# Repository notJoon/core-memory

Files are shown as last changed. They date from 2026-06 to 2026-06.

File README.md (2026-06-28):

# core-memory
ferrite core memory PCB &amp; firmware

## Gerber Files

Pre-generated Gerber files are in the `gerber/` directory and can be submitted to a PCB fabricator directly.

| File | Layer |
|---|---|
| `CoreMem-F_Cu.gbr` | Front copper |
| `CoreMem-B_Cu.gbr` | Back copper |
| `CoreMem-F_Mask.gbr` | Front solder mask |
| `CoreMem-B_Mask.gbr` | Back solder mask |
| `CoreMem-F_SilkS.gbr` | Front silkscreen |
| `CoreMem-B_SilkS.gbr` | Back silkscreen |
| `CoreMem-Edge_Cuts.gbr` | Board outline |
| `CoreMem-PTH.drl` | Plated drill holes |
| `CoreMem-NPTH.drl` | Non-plated drill holes |

Zip the contents of `gerber/` and upload the archive to your fabricator (JLCPCB, PCBWay, OSH Park, etc.).

### Regenerating Gerber Files

If you modify `CoreMem.kicad_pcb`, regenerate the files with KiCad 5 or later.

**Prerequisites:** [KiCad](https://www.kicad.org/) 5.x or later

1. Open `CoreMem.kicad_pcb` in KiCad PCB Editor (Pcbnew).
2. Go to **File** and select **Plot**.
3. Set the output directory to `gerber/`.
4. Select the following layers: `F.Cu`, `B.Cu`, `F.SilkS`, `B.SilkS`, `F.Mask`, `B.Mask`, `Edge.Cuts`.
5. Make sure **Use Protel filename extensions** is unchecked and **Generate Gerber job file** is unchecked.
6. Click **Plot**.
7. Click **Generate Drill Files**, keep the defaults, and click **Generate Drill File**.
8. Zip the `gerber/` directory and submit to your fabricator.

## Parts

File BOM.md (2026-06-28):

# Bill of Materials

## 능동 소자

| 수량 | 부품 | 설명 | 지정 파트 넘버 | 대안 부품 | 비고 |
|---|---|---|---|---|---|
| 2 | ICE40HX4K-TQ144 | FPGA | | | |
| 12 | OPA2365AIDR | 센스 앰프용 Op-Amp | | | |
| 10 | TS864 | 쿼드 비교기 | | TS864IDT | 동일 SOIC-14, 산업용 온도 범위(-40~85°C), 직접 교체 가능 |
| 20 | DMG6602SVTQ-7 | 듀얼 N+P ch MOSFET (드라이브) | | | |
| 6 | DMHC3025LSD-13 | 듀얼 P-ch MOSFET | | | |
| 4 | QS5K2 | N-ch MOSFET 어레이 | | | |
| 1 | DMG1012T-7 | N-ch MOSFET (SOT-523) | | | |
| 1 | MCP42010 | 듀얼 디지털 포텐시오미터 | MCP42010-I/SL | MCP42010-E/SL | MCP42010-E/P는 PDIP-14(스루홀)이므로 사용 불가 |
| 1 | W25Q32JVSSIQ_TR | 32Mbit SPI NOR Flash (FPGA 설정 저장) | | GD25Q32CSIG, GD25Q32ESIG, MX25L3206EM2I-12G, W25Q32FVSSIG, AT25SF321B-SHD-B | 단종. 대안 부품은 모두 SOIC-8 와이드(5.6mm) 패키지 확인 필수 |
| 1 | SiT2001B | 13.333MHz MEMS 오실레이터 | | | |
| 1 | LM338 | 조정형 LDO 5A (VDRIVE) | LM338T/NOPB | | 회로도에 이미 LM338T/NOPB 지정 |
| 1 | AZ1117-3.3 | 3.3V LDO | AZ1117EH-3.3TRG1 | | AZ1117CH-3.3TRG1은 패키지 불일치 가능성 있음(SOT-89 추정). 반드시 데이터시트에서 SOT-223 여부 확인 후 사용 |
| 1 | AZ1117-1.2 | 1.2V LDO | AZ1117EH-1.2TRG1 | | |

## 수동 소자

| 수량 | 부품 | 값 | 비고 |
|---|---|----|---|
| 24 | 저항 | 22k | |
| 15 | 저항 | 10k | |
| 14 | 저항 | 20Ω | |
| 8 | 저항 | 1k | |
| 4 | 저항 | 261Ω | |
| 4 | 저항 | 100Ω | |
| 1 | 저항 | 100k | |
| 2 | 트리머 저항 | 10k | |
| 2 | 저항 | 0Ω (점퍼) | |
| 2 | 저항 | DNP | 미실장 |
| 28 | 세라믹 커패시터 | 0.1uF | |
| 15 | 세라믹 커패시터 | 10uF | |
| 6 | 전해 커패시터 | 100uF | |
| 1 | 다이오드 | CDBU0520 | |
| 4 | LED | | 색상 임의 |

## 커넥터 및 기구

| 수량 | 부품 | 설명 |
|---|---|---|
| 1 | Conn 1x6 2.54mm | CTRL 커넥터 |
| 1 | Conn 2x4 2.54mm | PROG (FPGA 프로그래밍) |
| 1 | Conn 2x2 2.54mm | 기타 커넥터 |
| 1 | CoreArray | 코어 메모리 어레이 (수작업 권선) |

## 주의사항

- **FET 게이트 풀다운 누락**: `X0/X1_EN_F/R`, `Y0~Y3_EN_F/R` 신호(총 12개)에 풀다운 저항이 없음. FPGA 미설정 시 shoot-through 발생 가능. 10kΩ 저항 12개를 보드 수령 후 몸지 납땜으로 추가 권장 (위 BOM에 미포함).
- **W25Q32JVSSIQ_TR**: 단종 부품. 대안 부품 선택 시 SOIC-8 와이드(5.6mm) 패키지인지 반드시 확인.
- **AZ1117CH-3.3TRG1**: SOT-89 패키지로 추정되며 PCB 풋프린트(SOT-223-3)와 다를 수 있음. 구매 전 데이터시트 확인 필수.

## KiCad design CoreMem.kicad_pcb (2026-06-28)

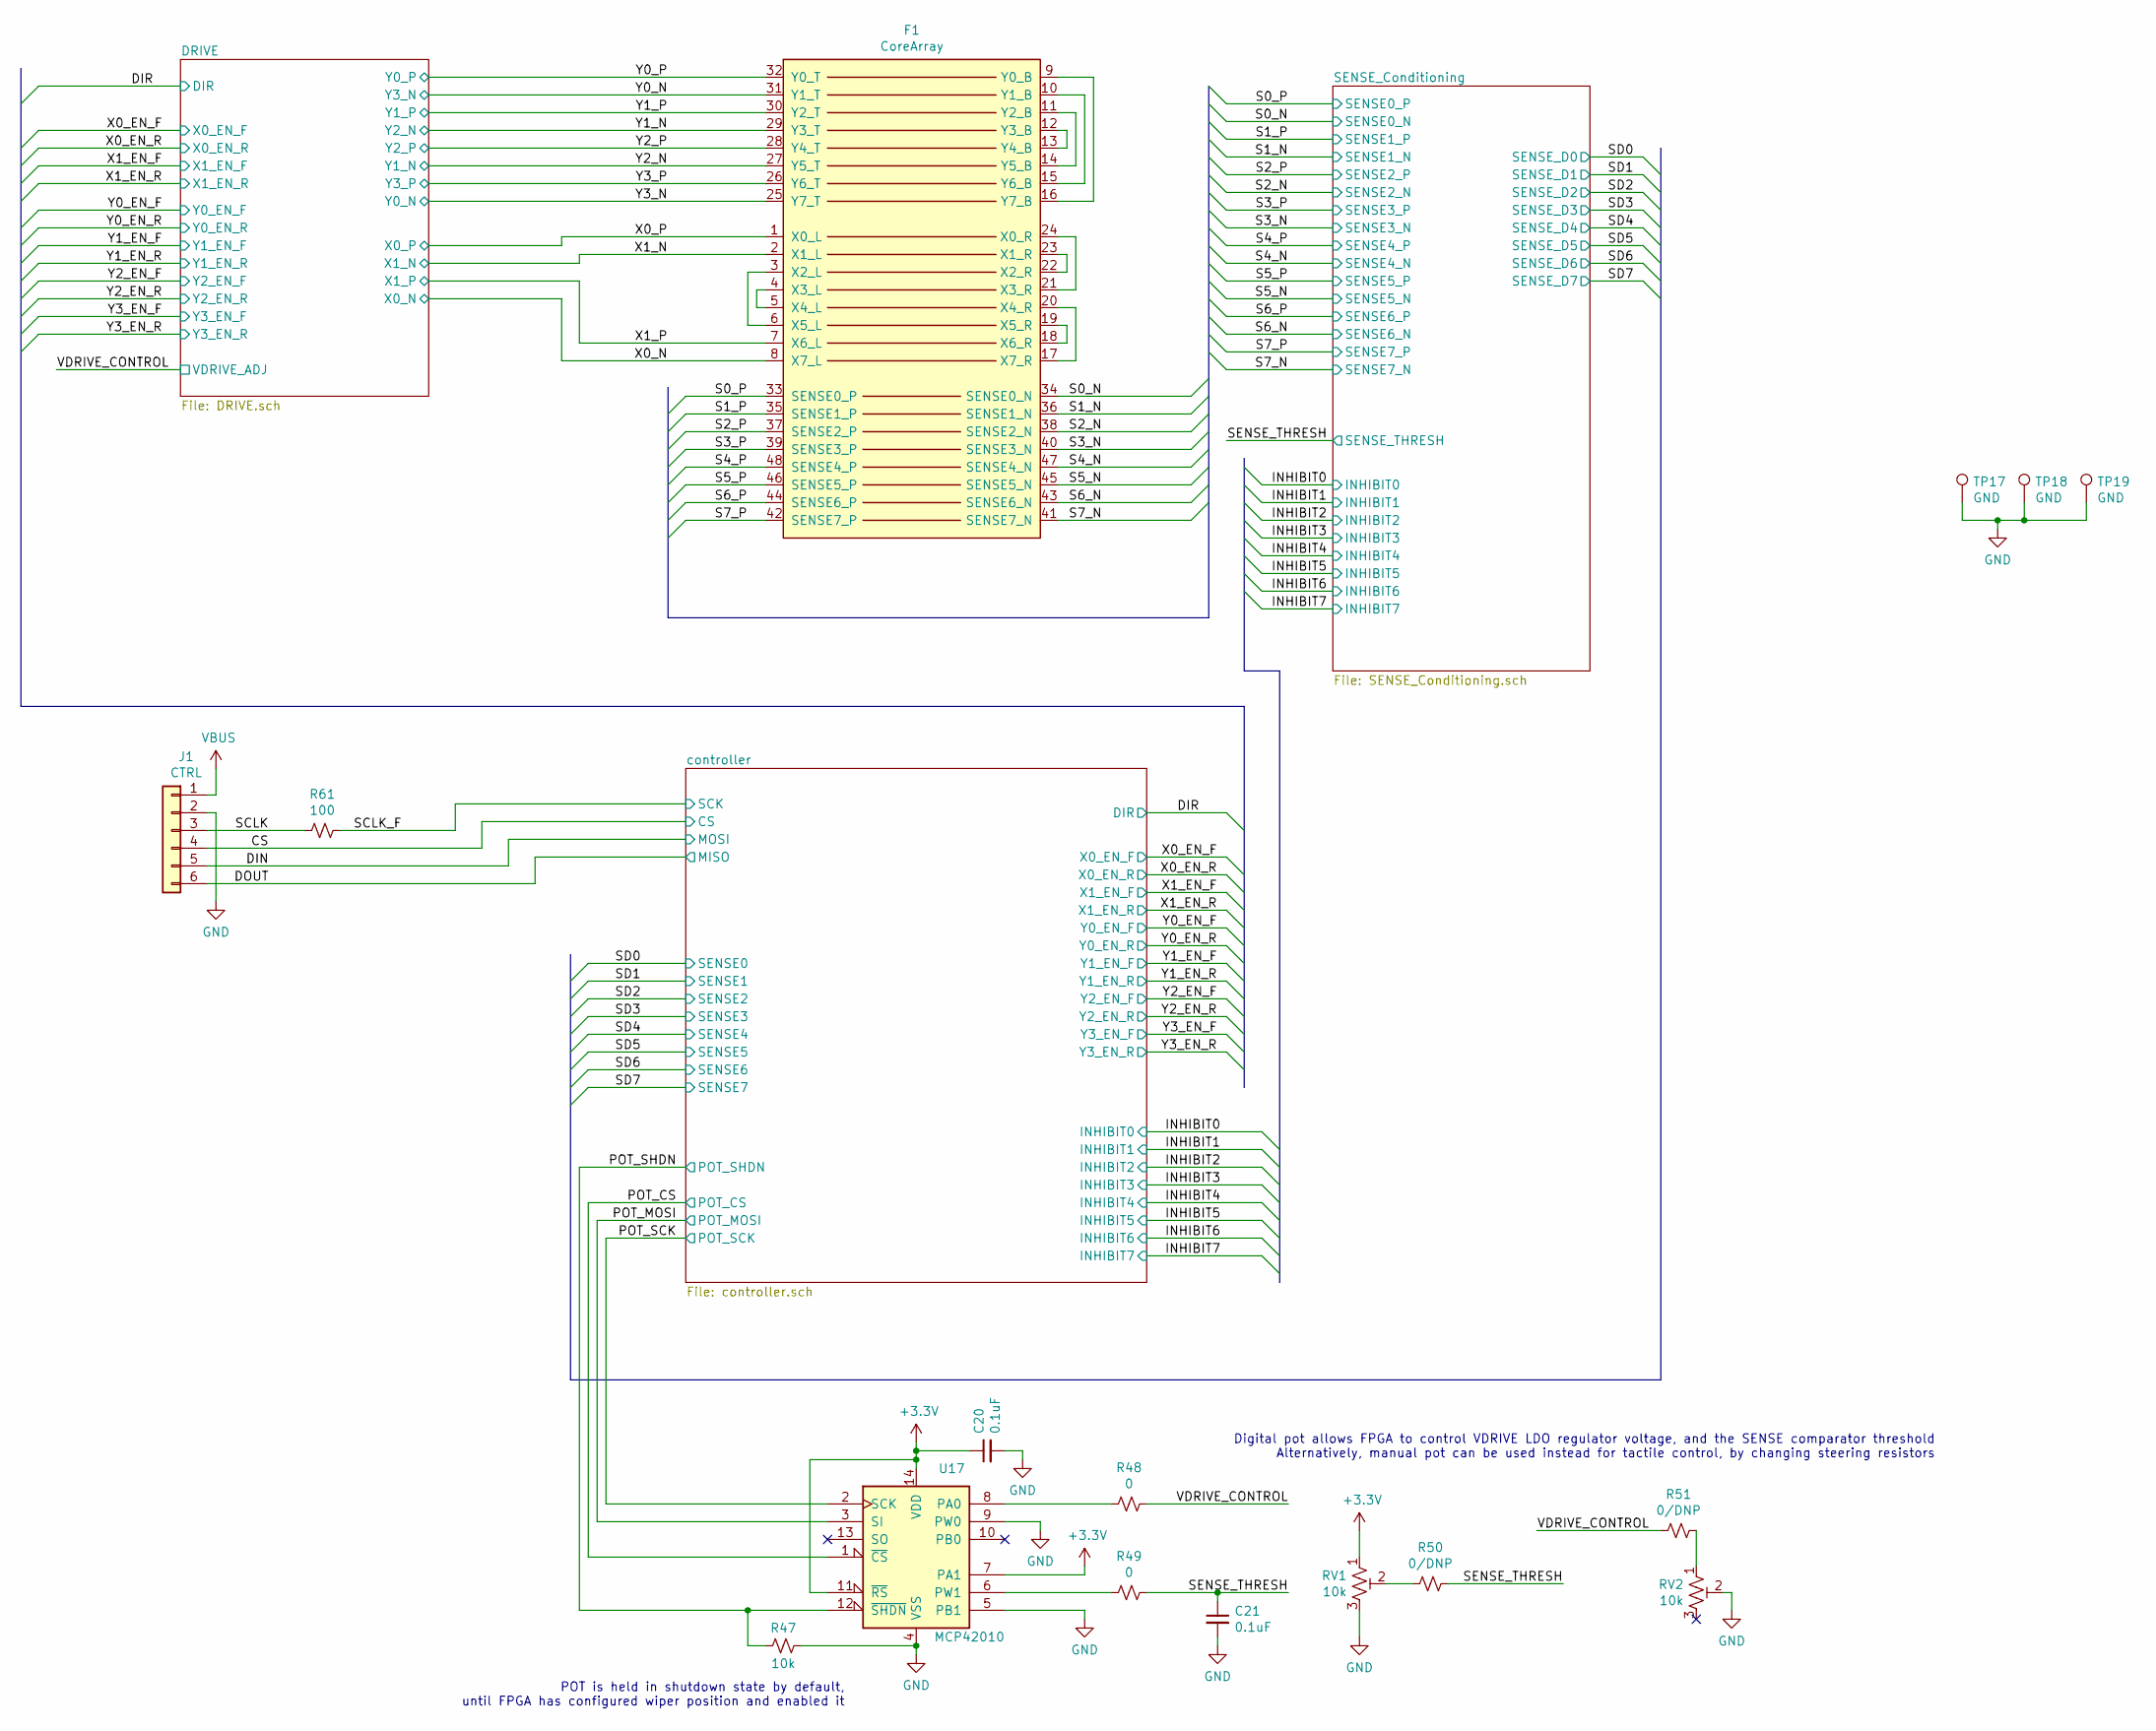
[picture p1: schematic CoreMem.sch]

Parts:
C20, C21: 0.1uF; C_0603_1608Metric_Pad1.05x0.95mm_HandSolder; Mfg Part Number CL10B104KA8NNNC
F1: CoreArray
J1: CTRL; PinHeader_1x06_P2.54mm_Vertical; Mfg Part Number 68000-406HLF
R47: 10k; R_0603_1608Metric_Pad1.05x0.95mm_HandSolder; Mfg Part Number ERJ-3EKF1002V
R48, R49: 0; R_0603_1608Metric_Pad1.05x0.95mm_HandSolder; Mfg Part Number ERJ-3GEY0R00V
R50, R51: 0/DNP; R_0603_1608Metric_Pad1.05x0.95mm_HandSolder; Mfg Part Number ERJ-3GEY0R00V
R61: 100; R_0603_1608Metric_Pad1.05x0.95mm_HandSolder; Mfg Part Number ERJ-3EKF1000V
RV1, RV2: 10k; ST4EB; Mfg Part Number ST4ETB103
TP17, TP18, TP19: GND; PinHeader_1x01_P2.54mm_Vertical
U17: MCP42010; SOIC-14_3.9x8.7mm_P1.27mm; Mfg Part Number MCP42010-I/SL

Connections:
+3V3: C20.1, RV1.1, U17.7 (PA1), U17.11 (~RS), U17.14 (VDD); also elsewhere on the board
/CS: J1.4; also elsewhere on the board
/DIN: J1.5; also elsewhere on the board
/DOUT: J1.6; also elsewhere on the board
/POT_CS: U17.1 (~CS); also elsewhere on the board
/POT_MOSI: U17.3 (SI); also elsewhere on the board
/POT_SCK: U17.2 (SCK); also elsewhere on the board
/POT_SHDN: R47.1, U17.12 (~SHDN); also elsewhere on the board
/S0_N: F1.34 (SENSE0_N); also elsewhere on the board
/S0_P: F1.33 (SENSE0_P); also elsewhere on the board
/S1_N: F1.36 (SENSE1_N); also elsewhere on the board
/S1_P: F1.35 (SENSE1_P); also elsewhere on the board
/S2_N: F1.38 (SENSE2_N); also elsewhere on the board
/S2_P: F1.37 (SENSE2_P); also elsewhere on the board
/S3_N: F1.40 (SENSE3_N); also elsewhere on the board
/S3_P: F1.39 (SENSE3_P); also elsewhere on the board
/S4_N: F1.47 (SENSE4_N); also elsewhere on the board
/S4_P: F1.48 (SENSE4_P); also elsewhere on the board
/S5_N: F1.45 (SENSE5_N); also elsewhere on the board
/S5_P: F1.46 (SENSE5_P); also elsewhere on the board
/S6_N: F1.43 (SENSE6_N); also elsewhere on the board
/S6_P: F1.44 (SENSE6_P); also elsewhere on the board
/S7_N: F1.41 (SENSE7_N); also elsewhere on the board
/S7_P: F1.42 (SENSE7_P); also elsewhere on the board
/SCLK: J1.3, R61.2
/SCLK_F: R61.1; also elsewhere on the board
/SENSE_THRESH: C21.1, R49.1, R50.1; also elsewhere on the board
/VDRIVE_CONTROL: R48.1, R51.2; also elsewhere on the board
/X0_N: F1.8 (X7_L); also elsewhere on the board
/X0_P: F1.1 (X0_L); also elsewhere on the board
/X1_N: F1.2 (X1_L); also elsewhere on the board
/X1_P: F1.7 (X6_L); also elsewhere on the board
/Y0_N: F1.31 (Y1_T); also elsewhere on the board
/Y0_P: F1.32 (Y0_T); also elsewhere on the board
/Y1_N: F1.29 (Y3_T); also elsewhere on the board
/Y1_P: F1.30 (Y2_T); also elsewhere on the board
/Y2_N: F1.27 (Y5_T); also elsewhere on the board
/Y2_P: F1.28 (Y4_T); also elsewhere on the board
/Y3_N: F1.25 (Y7_T); also elsewhere on the board
/Y3_P: F1.26 (Y6_T); also elsewhere on the board
GND: C20.2, C21.2, J1.2, R47.2, RV1.3, RV2.2, TP17.1, TP18.1, TP19.1, U17.4 (VSS), U17.5 (PB1), U17.9 (PW0); also elsewhere on the board
unnamed: F1.3 (X2_L), F1.6 (X5_L)
unnamed: F1.4 (X3_L), F1.5 (X4_L)
unnamed: F1.10 (Y1_B), F1.15 (Y6_B)
unnamed: F1.11 (Y2_B), F1.14 (Y5_B)
unnamed: F1.12 (Y3_B), F1.13 (Y4_B)
unnamed: F1.9 (Y0_B), F1.16 (Y7_B)
unnamed: F1.17 (X7_R), F1.20 (X4_R)
unnamed: F1.18 (X6_R), F1.19 (X5_R)
unnamed: F1.21 (X3_R), F1.24 (X0_R)
unnamed: F1.22 (X2_R), F1.23 (X1_R)
unnamed: R48.2, U17.8 (PA0)
unnamed: R49.2, U17.6 (PW1)
unnamed: R50.2, RV1.2
unnamed: R51.1, RV2.1
VBUS: J1.1; also elsewhere on the board

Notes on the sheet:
Digital pot allows FPGA to control VDRIVE LDO regulator voltage, and the SENSE comparator threshold Alternatively, manual pot can be used instead for tactile control, by changing steering resistors
POT is held in shutdown state by default, until FPGA has configured wiper position and enabled it

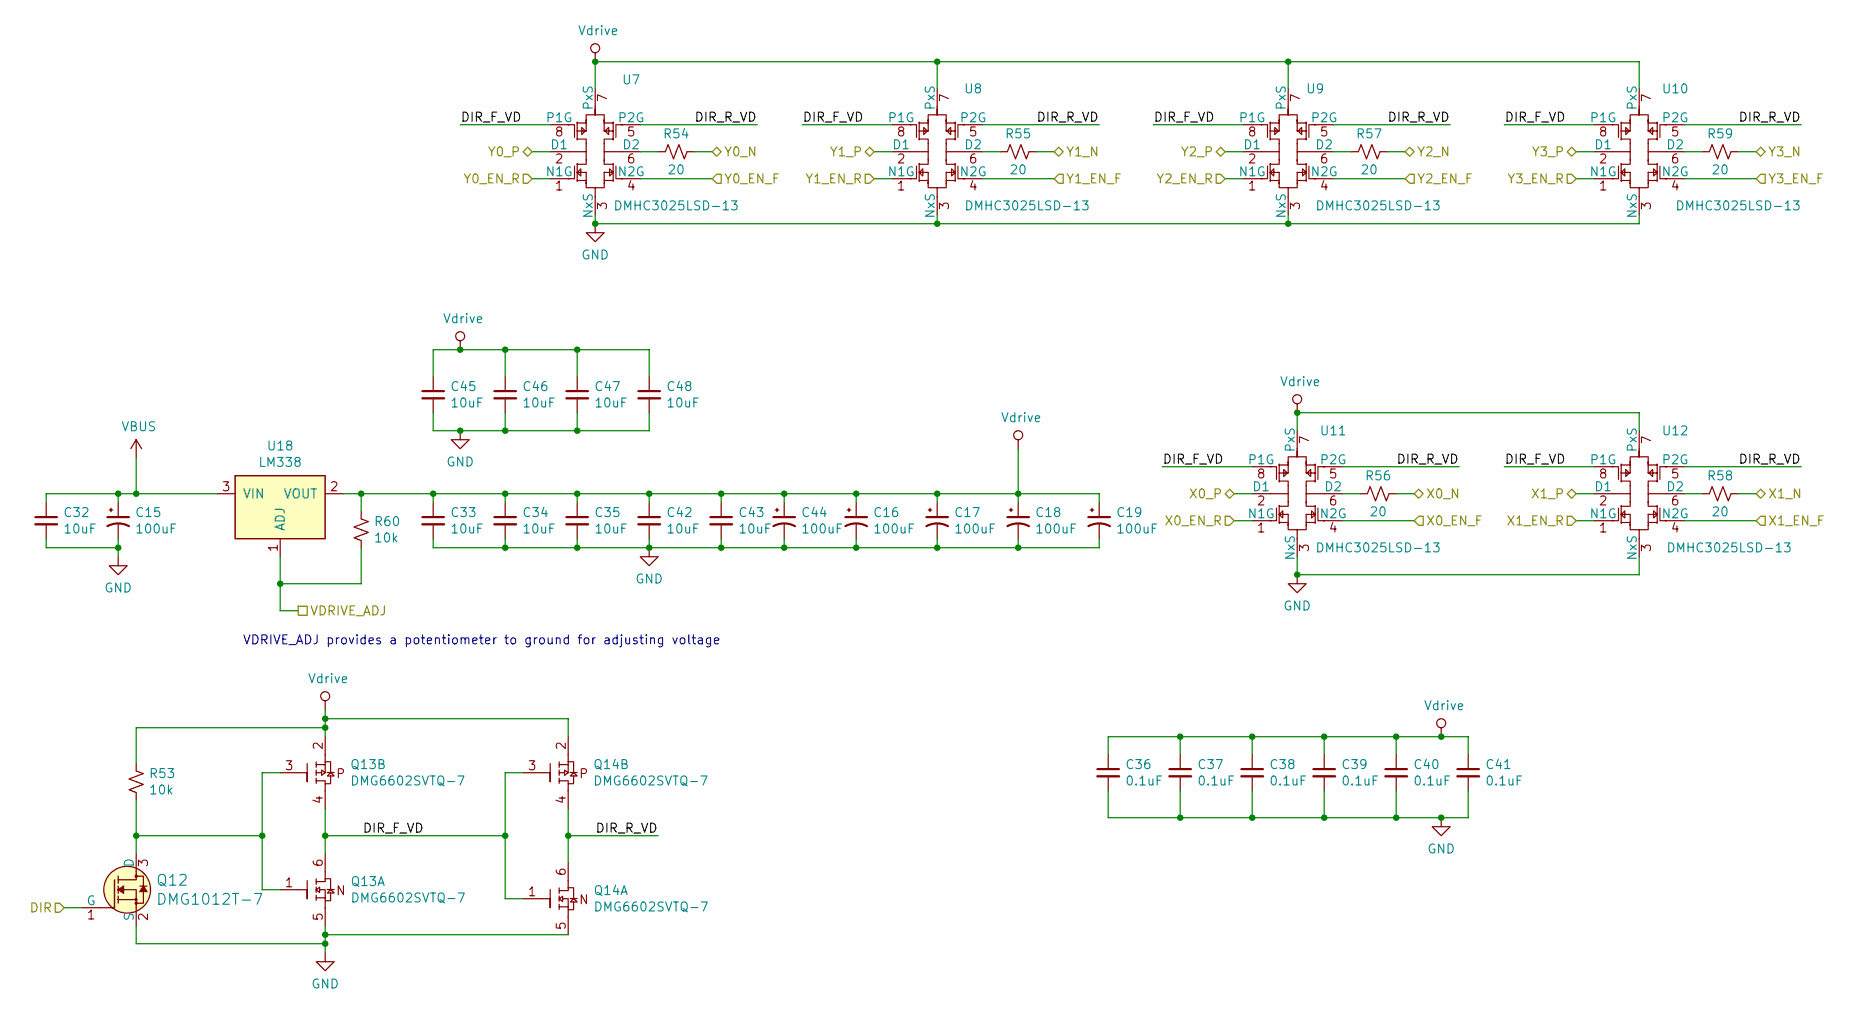
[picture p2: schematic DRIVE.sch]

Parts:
C15, C16, C17, C18, C19, C44: 100uF; C_Elec_6.3x7.7; Mfg Part Number UWT1E101MCL1GS
C32, C33, C34, C35, C42, C43, C45, C46, C47, C48: 10uF; C_1206_3216Metric_Pad1.42x1.75mm_HandSolder; Mfg Part Number CL31A106KAHNNNE
C36, C37, C38, C39, C40, C41: 0.1uF; C_0603_1608Metric_Pad1.05x0.95mm_HandSolder; Mfg Part Number CL10B104KA8NNNC
Q12: DMG1012T-7; SOT-523; MPN DMG1012T-7; Digi-Key_PN DMG1012T-7DICT-ND
Q13, Q14: DMG6602SVTQ-7; TSOT-23-6; Mfg Part Number DMG6602SVTQ-7
R53, R60: 10k; R_0603_1608Metric_Pad1.05x0.95mm_HandSolder; Mfg Part Number ERJ-3EKF1002V
R54, R55, R56, R57, R58, R59: 20; R_1206_3216Metric_Pad1.42x1.75mm_HandSolder; Mfg Part Number ESR18EZPF20R0
U7, U8, U9, U10, U11, U12: DMHC3025LSD-13‎; SOIC-8_3.9x4.9mm_P1.27mm; Mfg Part Number DMHC3025LSD-13
U18: LM338; TO-220-3_Vertical; Mfg Part Number LM338T/NOPB

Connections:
/DIR: Q12.1 (G); also elsewhere on the board
/DRIVE/DIR_F_VD: Q13.4 (D2), Q13.6 (D1), Q14.1 (G1), Q14.3 (G2), U7.8 (P1G), U8.8 (P1G), U9.8 (P1G), U10.8 (P1G), U11.8 (P1G), U12.8 (P1G)
/DRIVE/DIR_R_VD: Q14.4 (D2), Q14.6 (D1), U7.5 (P2G), U8.5 (P2G), U9.5 (P2G), U10.5 (P2G), U11.5 (P2G), U12.5 (P2G)
/VDRIVE_CONTROL: R60.2, U18.1 (ADJ); also elsewhere on the board
/X0_EN_F: U11.4 (N2G); also elsewhere on the board
/X0_EN_R: U11.1 (N1G); also elsewhere on the board
/X0_N: R56.1; also elsewhere on the board
/X0_P: U11.2 (D1); also elsewhere on the board
/X1_EN_F: U12.4 (N2G); also elsewhere on the board
/X1_EN_R: U12.1 (N1G); also elsewhere on the board
/X1_N: R58.1; also elsewhere on the board
/X1_P: U12.2 (D1); also elsewhere on the board
/Y0_EN_F: U7.4 (N2G); also elsewhere on the board
/Y0_EN_R: U7.1 (N1G); also elsewhere on the board
/Y0_N: R59.1; also elsewhere on the board
/Y0_P: U7.2 (D1); also elsewhere on the board
/Y1_EN_F: U8.4 (N2G); also elsewhere on the board
/Y1_EN_R: U8.1 (N1G); also elsewhere on the board
/Y1_N: R57.1; also elsewhere on the board
/Y1_P: U8.2 (D1); also elsewhere on the board
/Y2_EN_F: U9.4 (N2G); also elsewhere on the board
/Y2_EN_R: U9.1 (N1G); also elsewhere on the board
/Y2_N: R55.1; also elsewhere on the board
/Y2_P: U9.2 (D1); also elsewhere on the board
/Y3_EN_F: U10.4 (N2G); also elsewhere on the board
/Y3_EN_R: U10.1 (N1G); also elsewhere on the board
/Y3_N: R54.1; also elsewhere on the board
/Y3_P: U10.2 (D1); also elsewhere on the board
GND: C15.2, C16.2, C17.2, C18.2, C19.2, C32.2, C33.2, C34.2, C35.2, C36.2, C37.2, C38.2, C39.2, C40.2, C41.2, C42.2, C43.2, C44.2, C45.2, C46.2, C47.2, C48.2, Q12.2 (S), Q13.5 (S1), Q14.5 (S1), U7.3 (NxS), U8.3 (NxS), U9.3 (NxS), U10.3 (NxS), U11.3 (NxS), U12.3 (NxS); also elsewhere on the board
unnamed: Q12.3 (D), Q13.1 (G1), Q13.3 (G2), R53.2
unnamed: R54.2, U7.6 (D2)
unnamed: R55.2, U8.6 (D2)
unnamed: R56.2, U11.6 (D2)
unnamed: R57.2, U9.6 (D2)
unnamed: R58.2, U12.6 (D2)
unnamed: R59.2, U10.6 (D2)
VBUS: C15.1, C32.1, U18.3 (VIN); also elsewhere on the board
Vdrive: C16.1, C17.1, C18.1, C19.1, C33.1, C34.1, C35.1, C36.1, C37.1, C38.1, C39.1, C40.1, C41.1, C42.1, C43.1, C44.1, C45.1, C46.1, C47.1, C48.1, Q13.2 (S2), Q14.2 (S2), R53.1, R60.1, U7.7 (PxS), U8.7 (PxS), U9.7 (PxS), U10.7 (PxS), U11.7 (PxS), U12.7 (PxS), U18.2 (VOUT); also elsewhere on the board

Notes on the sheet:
VDRIVE_ADJ provides a potentiometer to ground for adjusting voltage

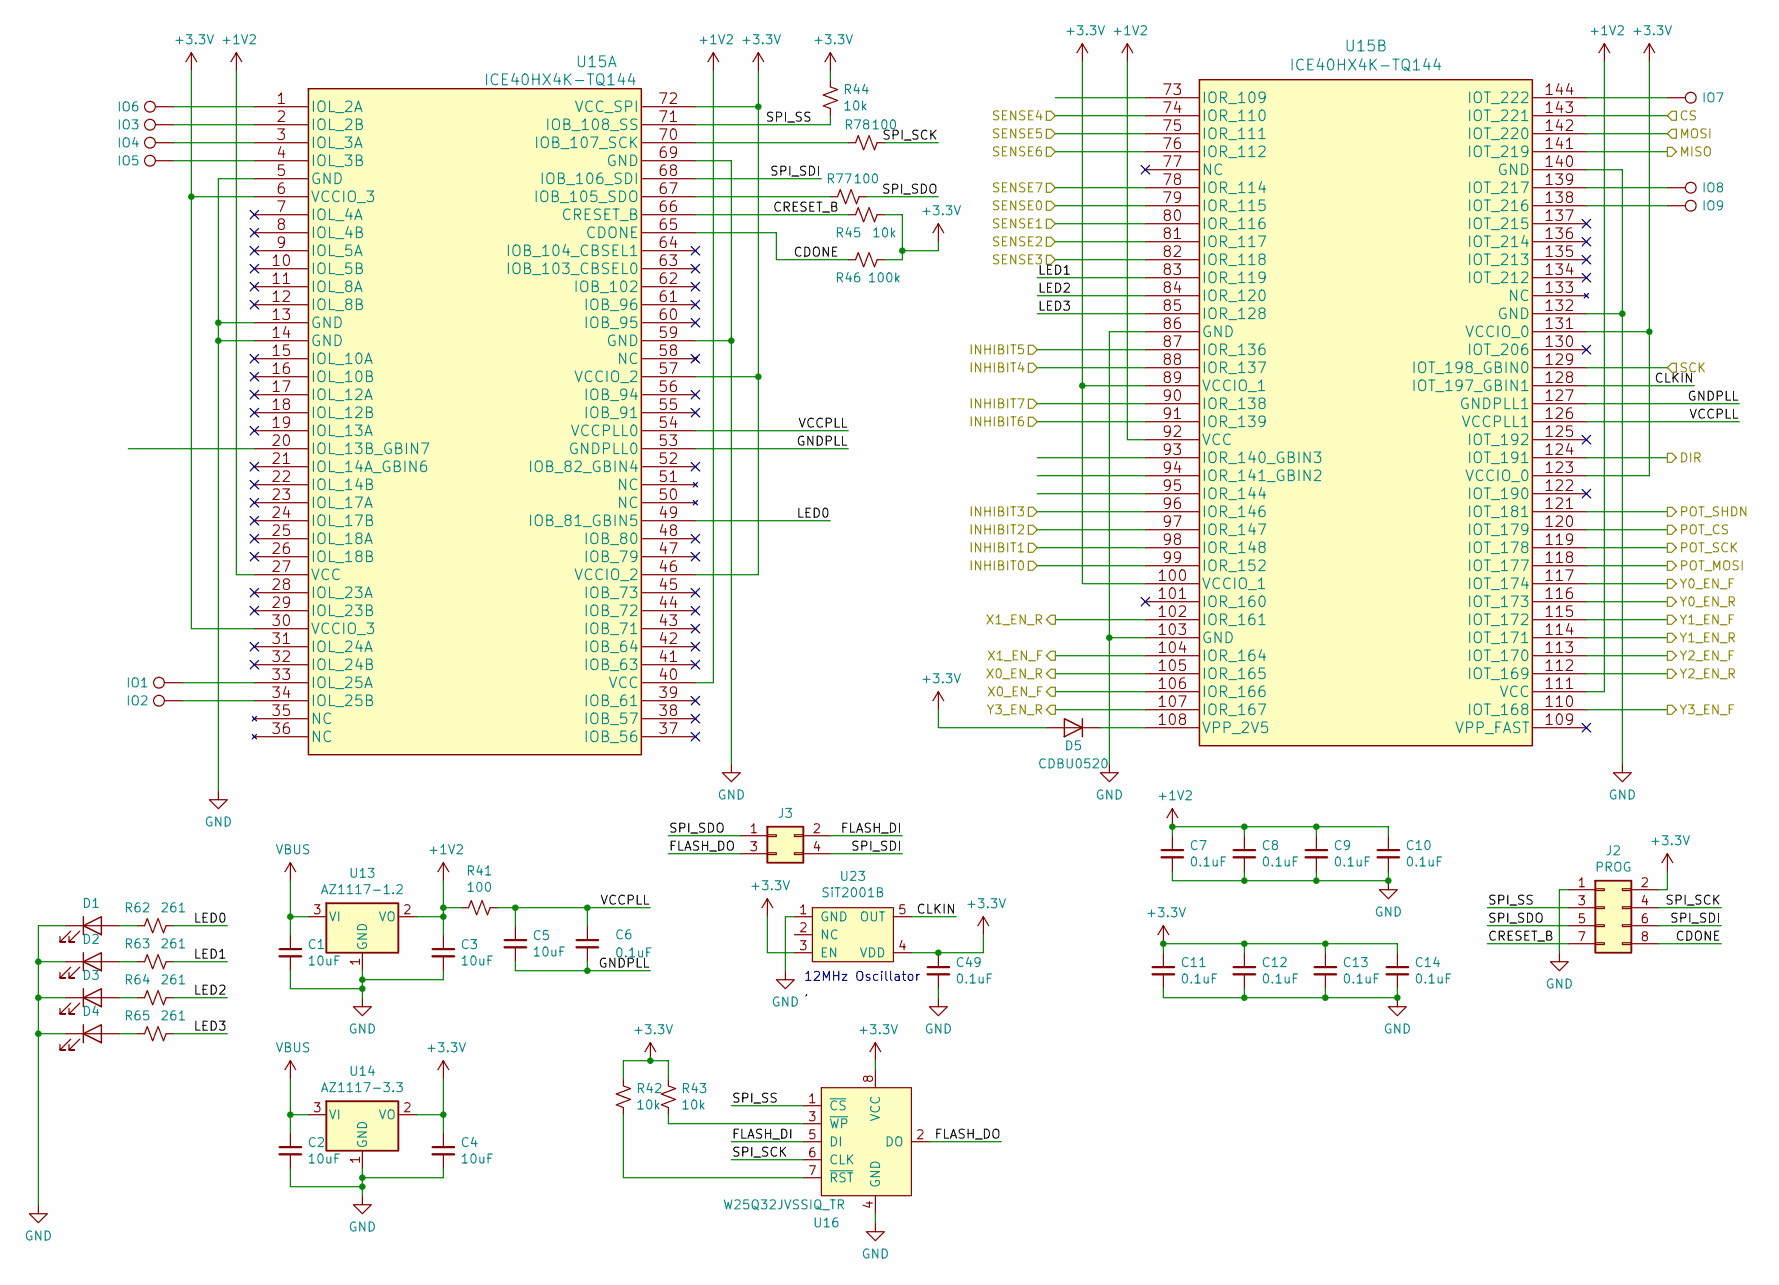
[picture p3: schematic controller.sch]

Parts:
C1, C2, C3, C4, C5: 10uF; C_1206_3216Metric_Pad1.42x1.75mm_HandSolder; Mfg Part Number CL31A106KAHNNNE
C6, C7, C8, C9, C10, C11, C12, C13, C14, C49: 0.1uF; C_0603_1608Metric_Pad1.05x0.95mm_HandSolder; Mfg Part Number CL10B104KA8NNNC
D1, D2, D3, D4: LED; LED_0603_1608Metric; Mfg Part Number 150060VS55040
D5: CDBU0520; D_0603_1608Metric; Mfg Part Number CDBU0520
IO1, IO2, IO3, IO4, IO5, IO6, IO7, IO8, IO9: TestPoint; TestPoint_THTPad_D1.0mm_Drill0.5mm
J2: PROG; PinHeader_2x04_P2.54mm_Vertical; Mfg Part Number 67997-208HLF
J3: Conn_02x02_Odd_Even; PinHeader_2x02_P2.54mm_Vertical; Mfg Part Number M20-9980245‎
R41, R77, R78: 100; R_0603_1608Metric_Pad1.05x0.95mm_HandSolder; Mfg Part Number ERJ-3EKF1000V
R42, R43, R44, R45: 10k; R_0603_1608Metric_Pad1.05x0.95mm_HandSolder; Mfg Part Number ERJ-3EKF1002V
R46: 100k; R_0603_1608Metric_Pad1.05x0.95mm_HandSolder; Mfg Part Number ERJ-3EKF1003V
R62, R63, R64, R65: 261; R_0603_1608Metric_Pad1.05x0.95mm_HandSolder; Mfg Part Number ERJ-3EKF2610V
U13: AZ1117-1.2; SOT-223-3_TabPin2; Mfg Part Number AZ1117EH-1.2TRG1
U14: AZ1117-3.3; SOT-223-3_TabPin2; Mfg Part Number AZ1117EH-3.3TRG1
U15: ICE40HX4K-TQ144; Mfg Part Number ICE40HX4K-TQ144
U16: W25Q32JVSSIQ_TR; SOIC-8_W5.6mm; MPN W25Q32JVSSIQ TR; Digi-Key_PN W25Q32JVSSIQCT-ND
U23: SiT2001B; TSOT-23-5; Mfg Part Number SIT2001BI-S2-33E-12.000000D

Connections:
+1V2: C3.1, C7.1, C8.1, C9.1, C10.1, R41.2, U13.2 (VO), U15.27 (VCC), U15.40 (VCC), U15.92 (VCC), U15.111 (VCC)
+3V3: C4.1, C11.1, C12.1, C13.1, C14.1, C49.1, D5.2 (A), J2.2, R42.2, R43.2, R44.2, R45.2, R46.2, U14.2 (VO), U15.6 (VCCIO_3), U15.30 (VCCIO_3), U15.46 (VCCIO_2), U15.57 (VCCIO_2), U15.72 (VCC_SPI), U15.89 (VCCIO_1), U15.100 (VCCIO_1), U15.123 (VCCIO_0), U15.131 (VCCIO_0), U16.8 (VCC), U23.3 (EN), U23.4 (VDD); also elsewhere on the board
/CS: U15.143 (IOT_221); also elsewhere on the board
/DIN: U15.142 (IOT_220); also elsewhere on the board
/DIR: U15.124 (IOT_191); also elsewhere on the board
/DOUT: U15.141 (IOT_219); also elsewhere on the board
/INHIBIT0: U15.99 (IOR_152); also elsewhere on the board
/INHIBIT1: U15.98 (IOR_148); also elsewhere on the board
/INHIBIT2: U15.97 (IOR_147); also elsewhere on the board
/INHIBIT3: U15.96 (IOR_146); also elsewhere on the board
/INHIBIT4: U15.88 (IOR_137); also elsewhere on the board
/INHIBIT5: U15.87 (IOR_136); also elsewhere on the board
/INHIBIT6: U15.91 (IOR_139); also elsewhere on the board
/INHIBIT7: U15.90 (IOR_138); also elsewhere on the board
/POT_CS: U15.120 (IOT_179); also elsewhere on the board
/POT_MOSI: U15.118 (IOT_177); also elsewhere on the board
/POT_SCK: U15.119 (IOT_178); also elsewhere on the board
/POT_SHDN: U15.121 (IOT_181); also elsewhere on the board
/SCLK_F: U15.129 (IOT_198_GBIN0); also elsewhere on the board
/SD0: U15.79 (IOR_115); also elsewhere on the board
/SD1: U15.80 (IOR_116); also elsewhere on the board
/SD2: U15.81 (IOR_117); also elsewhere on the board
/SD3: U15.82 (IOR_118); also elsewhere on the board
/SD4: U15.74 (IOR_110); also elsewhere on the board
/SD5: U15.75 (IOR_111); also elsewhere on the board
/SD6: U15.76 (IOR_112); also elsewhere on the board
/SD7: U15.78 (IOR_114); also elsewhere on the board
/X0_EN_F: U15.106 (IOR_166); also elsewhere on the board
/X0_EN_R: U15.105 (IOR_165); also elsewhere on the board
/X1_EN_F: U15.104 (IOR_164); also elsewhere on the board
/X1_EN_R: U15.102 (IOR_161); also elsewhere on the board
/Y0_EN_F: U15.117 (IOT_174); also elsewhere on the board
/Y0_EN_R: U15.116 (IOT_173); also elsewhere on the board
/Y1_EN_F: U15.115 (IOT_172); also elsewhere on the board
/Y1_EN_R: U15.114 (IOT_171); also elsewhere on the board
/Y2_EN_F: U15.113 (IOT_170); also elsewhere on the board
/Y2_EN_R: U15.112 (IOT_169); also elsewhere on the board
/Y3_EN_F: U15.110 (IOT_168); also elsewhere on the board
/Y3_EN_R: U15.107 (IOR_167); also elsewhere on the board
/controller/CDONE: J2.8, R46.1, U15.65 (CDONE)
/controller/CLKIN: U15.128 (IOT_197_GBIN1), U23.5 (OUT)
/controller/CRESET_B: J2.7, R45.1, U15.66 (CRESET_B)
/controller/FLASH_DI: J3.2, U16.5 (DI)
/controller/FLASH_DO: J3.3, U16.2 (DO)
/controller/GNDPLL: C5.2, C6.2, U15.53 (GNDPLL0), U15.127 (GNDPLL1)
/controller/LED0: R62.1, U15.49 (IOB_81_GBIN5)
/controller/LED1: R63.1, U15.83 (IOR_119)
/controller/LED2: R64.1, U15.84 (IOR_120)
/controller/LED3: R65.1, U15.85 (IOR_128)
/controller/SPI_SCK: J2.4, R78.1, U16.6 (CLK)
/controller/SPI_SDI: J2.6, J3.4, U15.68 (IOB_106_SDI)
/controller/SPI_SDO: J2.5, J3.1, R77.1
/controller/SPI_SS: J2.3, R44.1, U15.71 (IOB_108_SS), U16.1 (~CS)
/controller/VCCPLL: C5.1, C6.1, R41.1, U15.54 (VCCPLL0), U15.126 (VCCPLL1)
GND: C1.2, C2.2, C3.2, C4.2, C7.2, C8.2, C9.2, C10.2, C11.2, C12.2, C13.2, C14.2, C49.2, D1.1 (K), D2.1 (K), D3.1 (K), D4.1 (K), J2.1, U13.1 (GND), U14.1 (GND), U15.5 (GND), U15.13 (GND), U15.14 (GND), U15.59 (GND), U15.69 (GND), U15.86 (GND), U15.103 (GND), U15.132 (GND), U15.140 (GND), U16.4 (GND), U23.1 (GND); also elsewhere on the board
unnamed: D1.2 (A), R62.2
unnamed: D2.2 (A), R63.2
unnamed: D3.2 (A), R64.2
unnamed: D4.2 (A), R65.2
unnamed: D5.1 (K), U15.108 (VPP_2V5)
unnamed: IO1.1, U15.33 (IOL_25A)
unnamed: IO2.1, U15.34 (IOL_25B)
unnamed: IO3.1, U15.2 (IOL_2B)
unnamed: IO4.1, U15.3 (IOL_3A)
unnamed: IO5.1, U15.4 (IOL_3B)
unnamed: IO6.1, U15.1 (IOL_2A)
unnamed: IO7.1, U15.144 (IOT_222)
unnamed: IO8.1, U15.139 (IOT_217)
unnamed: IO9.1, U15.138 (IOT_216)
unnamed: R42.1, U16.7 (~RST)
unnamed: R43.1, U16.3 (~WP)
unnamed: R77.2, U15.67 (IOB_105_SDO)
unnamed: R78.2, U15.70 (IOB_107_SCK)
VBUS: C1.1, C2.1, U13.3 (VI), U14.3 (VI); also elsewhere on the board

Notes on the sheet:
12MHz Oscillator ,

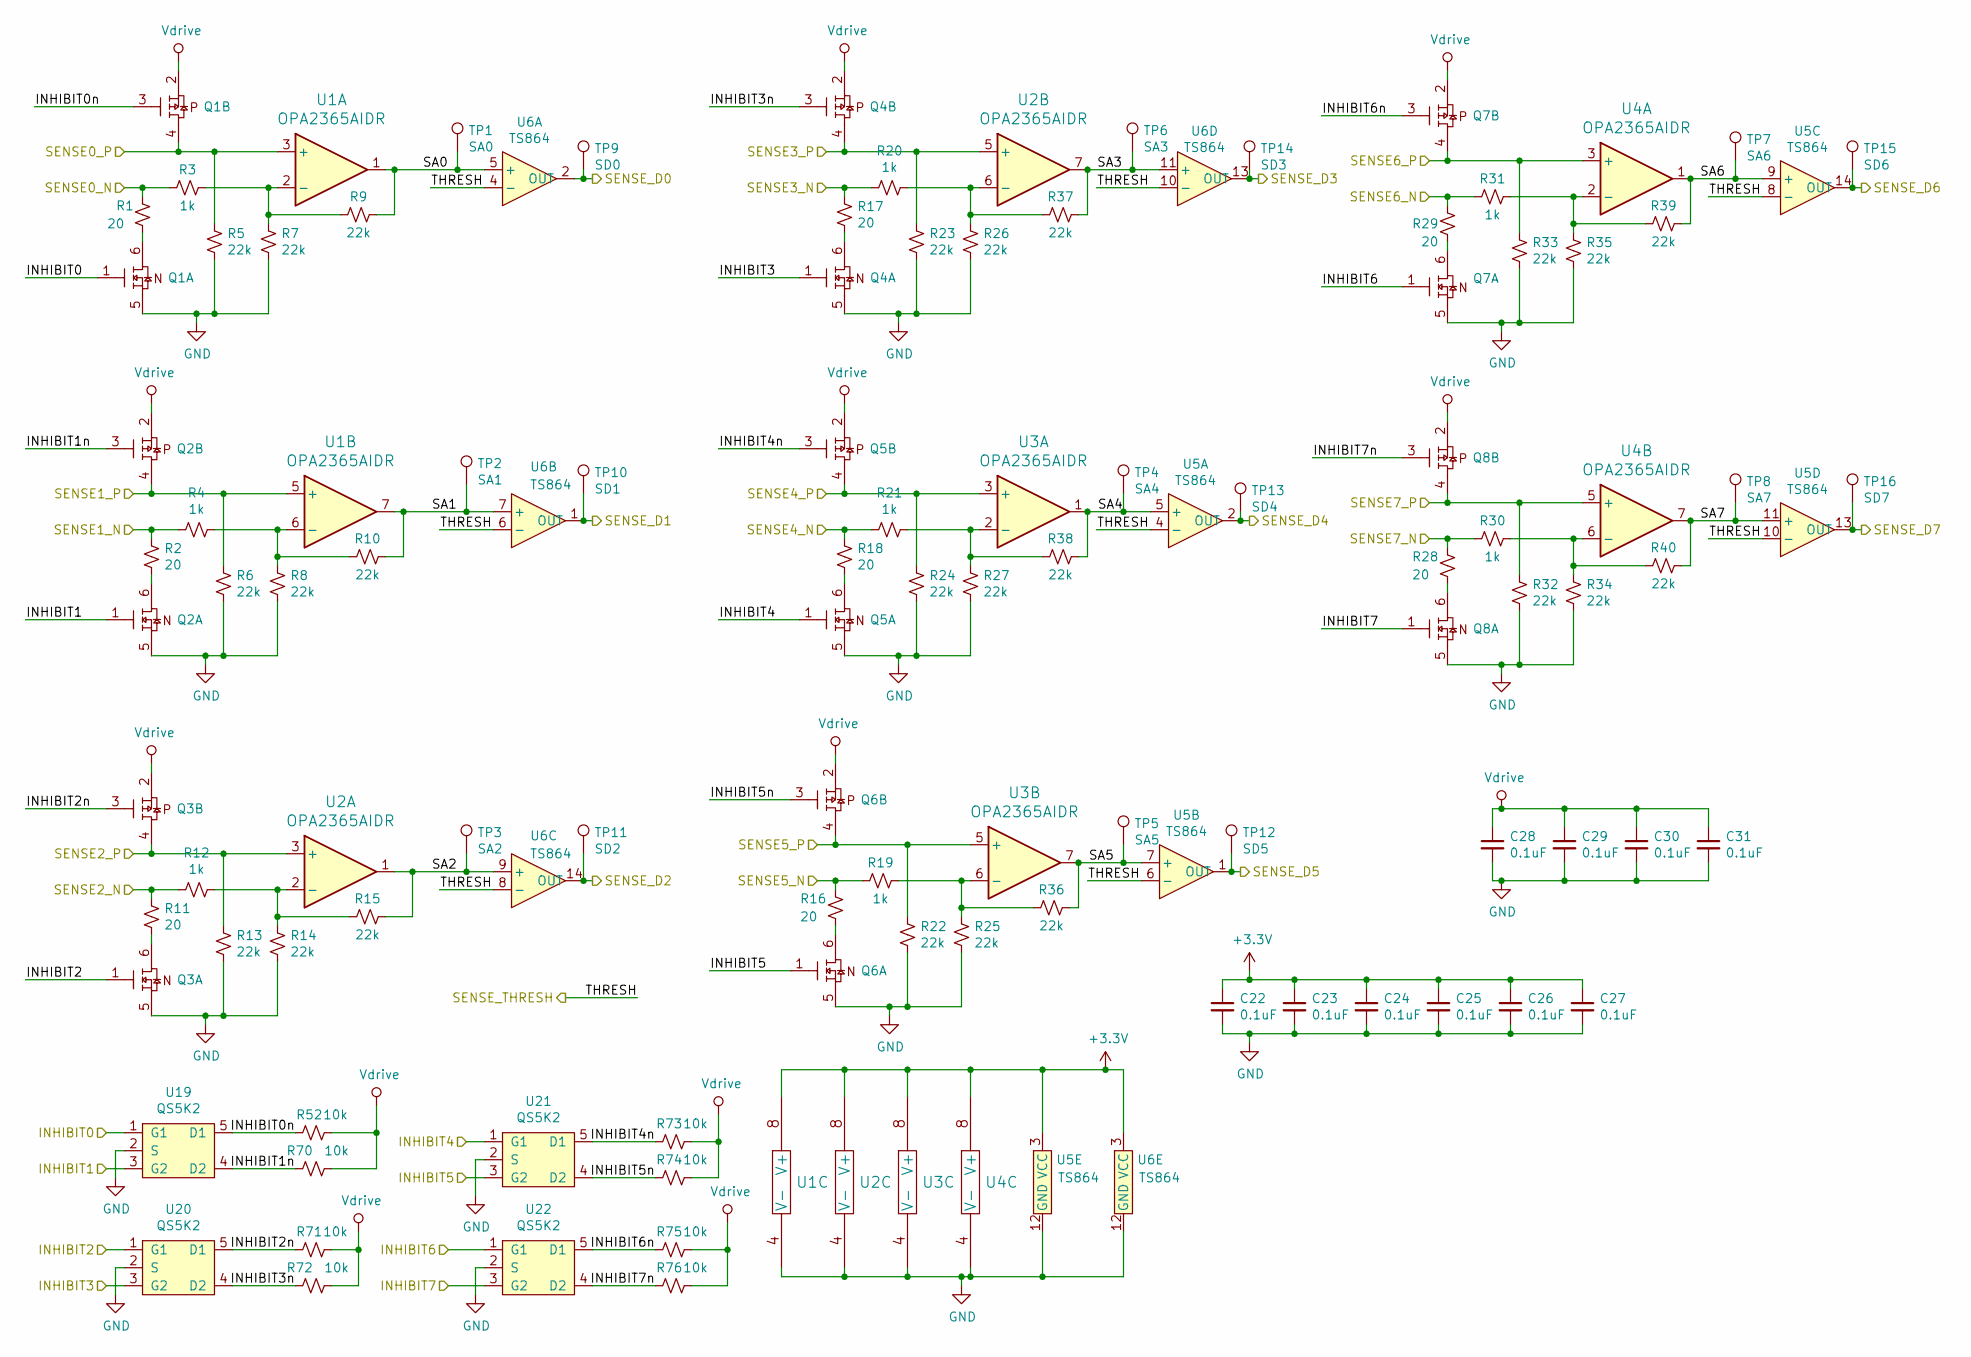
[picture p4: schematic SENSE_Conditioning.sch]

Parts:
C22, C23, C24, C25, C26, C27, C28, C29, C30, C31: 0.1uF; C_0603_1608Metric_Pad1.05x0.95mm_HandSolder; Mfg Part Number CL10B104KA8NNNC
Q1, Q2, Q3, Q4, Q5, Q6, Q7, Q8: DMG6602SVTQ-7; TSOT-23-6; Mfg Part Number DMG6602SVTQ-7
R1, R2, R11, R16, R17, R18, R28, R29: 20; R_1206_3216Metric_Pad1.42x1.75mm_HandSolder; Mfg Part Number ESR18EZPF20R0
R3, R4, R12, R19, R20, R21, R30, R31: 1k; R_0603_1608Metric_Pad1.05x0.95mm_HandSolder; Mfg Part Number ESR03EZPF1001
R5, R6, R7, R8, R9, R10, R13, R14, R15, R22, R23, R24, R25, R26, R27, R32, R33, R34, R35, R36, R37, R38, R39, R40: 22k; R_0603_1608Metric_Pad1.05x0.95mm_HandSolder; Mfg Part Number ERJ-3EKF2202V
R52, R70, R71, R72, R73, R74, R75, R76: 10k; R_0603_1608Metric_Pad1.05x0.95mm_HandSolder; Mfg Part Number ERJ-3EKF1002V
TP1: SA0; TestPoint_THTPad_D1.0mm_Drill0.5mm
TP2: SA1; TestPoint_THTPad_D1.0mm_Drill0.5mm
TP3: SA2; TestPoint_THTPad_D1.0mm_Drill0.5mm
TP4: SA4; TestPoint_THTPad_D1.0mm_Drill0.5mm
TP5: SA5; TestPoint_THTPad_D1.0mm_Drill0.5mm
TP6: SA3; TestPoint_THTPad_D1.0mm_Drill0.5mm
TP7: SA6; TestPoint_THTPad_D1.0mm_Drill0.5mm
TP8: SA7; TestPoint_THTPad_D1.0mm_Drill0.5mm
TP9: SD0; TestPoint_THTPad_D1.0mm_Drill0.5mm
TP10: SD1; TestPoint_THTPad_D1.0mm_Drill0.5mm
TP11: SD2; TestPoint_THTPad_D1.0mm_Drill0.5mm
TP12: SD5; TestPoint_THTPad_D1.0mm_Drill0.5mm
TP13: SD4; TestPoint_THTPad_D1.0mm_Drill0.5mm
TP14: SD3; TestPoint_THTPad_D1.0mm_Drill0.5mm
TP15: SD6; TestPoint_THTPad_D1.0mm_Drill0.5mm
TP16: SD7; TestPoint_THTPad_D1.0mm_Drill0.5mm
U1, U2, U3, U4: OPA2365AIDR; SOIC-8_3.9x4.9mm_P1.27mm; Mfg Part Number OPA2365AIDR
U5, U6: TS864; SOIC-14_3.9x8.7mm_P1.27mm; Mfg Part Number TS864IDT
U19, U20, U21, U22: QS5K2; TSOT-23-5; Mfg Part Number QS5K2TR

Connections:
+3V3: C22.1, C23.1, C24.1, C25.1, C26.1, C27.1, U1.8 (V+), U2.8 (V+), U3.8 (V+), U4.8 (V+), U5.3 (VCC), U6.3 (VCC); also elsewhere on the board
/INHIBIT0: Q1.1 (G1), U19.1 (G1); also elsewhere on the board
/INHIBIT1: Q2.1 (G1), U19.3 (G2); also elsewhere on the board
/INHIBIT2: Q3.1 (G1), U20.1 (G1); also elsewhere on the board
/INHIBIT3: Q4.1 (G1), U20.3 (G2); also elsewhere on the board
/INHIBIT4: Q5.1 (G1), U21.1 (G1); also elsewhere on the board
/INHIBIT5: Q6.1 (G1), U21.3 (G2); also elsewhere on the board
/INHIBIT6: Q7.1 (G1), U22.1 (G1); also elsewhere on the board
/INHIBIT7: Q8.1 (G1), U22.3 (G2); also elsewhere on the board
/S0_N: R1.2, R3.2; also elsewhere on the board
/S0_P: Q1.4 (D2), R5.2, U1.3 (+); also elsewhere on the board
/S1_N: R2.2, R4.2; also elsewhere on the board
/S1_P: Q2.4 (D2), R6.2, U1.5 (+); also elsewhere on the board
/S2_N: R11.2, R12.2; also elsewhere on the board
/S2_P: Q3.4 (D2), R13.2, U2.3 (+); also elsewhere on the board
/S3_N: R17.2, R20.2; also elsewhere on the board
/S3_P: Q4.4 (D2), R23.2, U2.5 (+); also elsewhere on the board
/S4_N: R18.2, R21.2; also elsewhere on the board
/S4_P: Q5.4 (D2), R24.2, U3.3 (+); also elsewhere on the board
/S5_N: R16.2, R19.2; also elsewhere on the board
/S5_P: Q6.4 (D2), R22.2, U3.5 (+); also elsewhere on the board
/S6_N: R29.2, R31.2; also elsewhere on the board
/S6_P: Q7.4 (D2), R33.2, U4.3 (+); also elsewhere on the board
/S7_N: R28.2, R30.2; also elsewhere on the board
/S7_P: Q8.4 (D2), R32.2, U4.5 (+); also elsewhere on the board
/SD0: TP9.1, U6.2 (OUT); also elsewhere on the board
/SD1: TP10.1, U6.1 (OUT); also elsewhere on the board
/SD2: TP11.1, U6.14 (OUT); also elsewhere on the board
/SD3: TP14.1, U6.13 (OUT); also elsewhere on the board
/SD4: TP13.1, U5.2 (OUT); also elsewhere on the board
/SD5: TP12.1, U5.1 (OUT); also elsewhere on the board
/SD6: TP15.1, U5.14 (OUT); also elsewhere on the board
/SD7: TP16.1, U5.13 (OUT); also elsewhere on the board
/SENSE_Conditioning/INHIBIT0n: Q1.3 (G2), R52.1, U19.5 (D1)
/SENSE_Conditioning/INHIBIT1n: Q2.3 (G2), R70.2, U19.4 (D2)
/SENSE_Conditioning/INHIBIT2n: Q3.3 (G2), R71.1, U20.5 (D1)
/SENSE_Conditioning/INHIBIT3n: Q4.3 (G2), R72.2, U20.4 (D2)
/SENSE_Conditioning/INHIBIT4n: Q5.3 (G2), R73.1, U21.5 (D1)
/SENSE_Conditioning/INHIBIT5n: Q6.3 (G2), R74.1, U21.4 (D2)
/SENSE_Conditioning/INHIBIT6n: Q7.3 (G2), R75.1, U22.5 (D1)
/SENSE_Conditioning/INHIBIT7n: Q8.3 (G2), R76.1, U22.4 (D2)
/SENSE_Conditioning/SA0: R9.2, TP1.1, U1.1, U6.5 (+)
/SENSE_Conditioning/SA1: R10.2, TP2.1, U1.7, U6.7 (+)
/SENSE_Conditioning/SA2: R15.2, TP3.1, U2.1, U6.9 (+)
/SENSE_Conditioning/SA3: R37.2, TP6.1, U2.7, U6.11 (+)
/SENSE_Conditioning/SA4: R38.2, TP4.1, U3.1, U5.5 (+)
/SENSE_Conditioning/SA5: R36.2, TP5.1, U3.7, U5.7 (+)
/SENSE_Conditioning/SA6: R39.2, TP7.1, U4.1, U5.9 (+)
/SENSE_Conditioning/SA7: R40.2, TP8.1, U4.7, U5.11 (+)
/SENSE_THRESH: U5.4 (-), U5.6 (-), U5.8 (-), U5.10 (-), U6.4 (-), U6.6 (-), U6.8 (-), U6.10 (-); also elsewhere on the board
GND: C22.2, C23.2, C24.2, C25.2, C26.2, C27.2, C28.2, C29.2, C30.2, C31.2, Q1.5 (S1), Q2.5 (S1), Q3.5 (S1), Q4.5 (S1), Q5.5 (S1), Q6.5 (S1), Q7.5 (S1), Q8.5 (S1), R5.1, R6.1, R7.1, R8.1, R13.1, R14.1, R22.1, R23.1, R24.1, R25.1, R26.1, R27.1, R32.1, R33.1, R34.1, R35.1, U1.4 (V-), U2.4 (V-), U3.4 (V-), U4.4 (V-), U5.12 (GND), U6.12 (GND), U19.2 (S), U20.2 (S), U21.2 (S), U22.2 (S); also elsewhere on the board
unnamed: Q1.6 (D1), R1.1
unnamed: Q2.6 (D1), R2.1
unnamed: Q3.6 (D1), R11.1
unnamed: Q4.6 (D1), R17.1
unnamed: Q5.6 (D1), R18.1
unnamed: Q6.6 (D1), R16.1
unnamed: Q7.6 (D1), R29.1
unnamed: Q8.6 (D1), R28.1
unnamed: R3.1, R7.2, R9.1, U1.2 (-)
unnamed: R4.1, R8.2, R10.1, U1.6 (-)
unnamed: R12.1, R14.2, R15.1, U2.2 (-)
unnamed: R19.1, R25.2, R36.1, U3.6 (-)
unnamed: R20.1, R26.2, R37.1, U2.6 (-)
unnamed: R21.1, R27.2, R38.1, U3.2 (-)
unnamed: R30.1, R34.2, R40.1, U4.6 (-)
unnamed: R31.1, R35.2, R39.1, U4.2 (-)
Vdrive: C28.1, C29.1, C30.1, C31.1, Q1.2 (S2), Q2.2 (S2), Q3.2 (S2), Q4.2 (S2), Q5.2 (S2), Q6.2 (S2), Q7.2 (S2), Q8.2 (S2), R52.2, R70.1, R71.2, R72.1, R73.2, R74.2, R75.2, R76.2; also elsewhere on the board

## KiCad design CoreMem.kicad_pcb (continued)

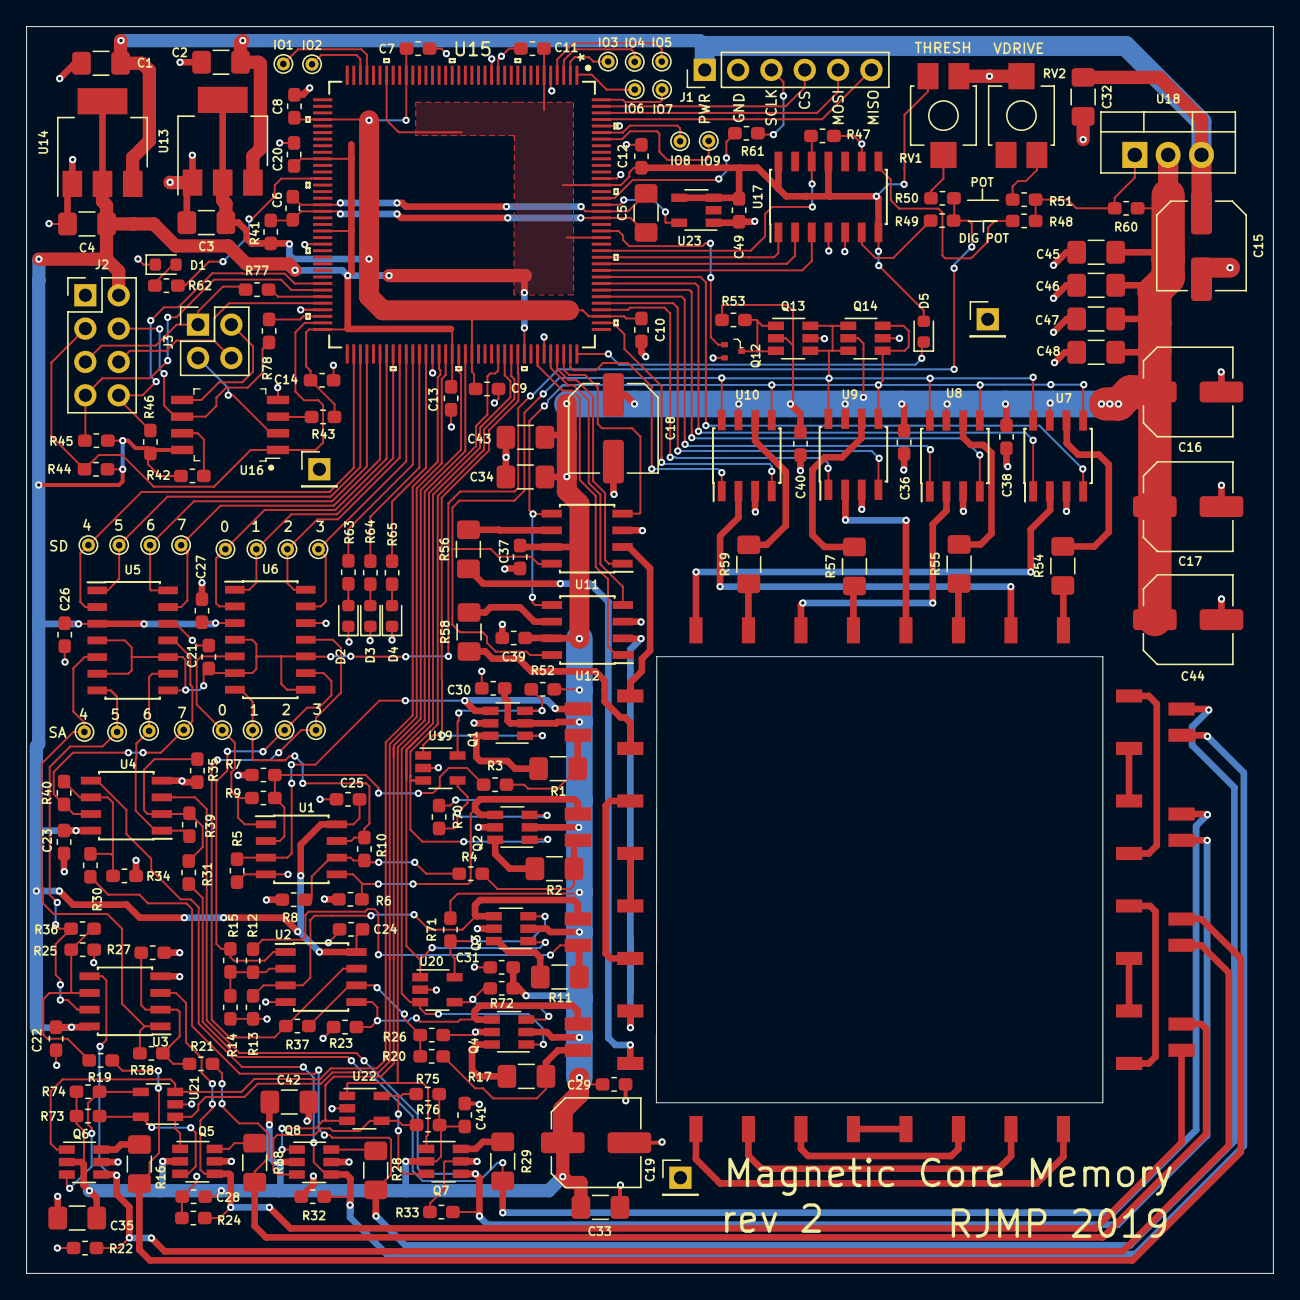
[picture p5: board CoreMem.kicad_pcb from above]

Board: 2 copper layers, 95.0 x 95.0 mm, 196 parts (0 on the bottom side), 161 nets.

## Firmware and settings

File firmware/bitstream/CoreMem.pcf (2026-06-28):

set_io CLKIN 128
set_io SCLK 129
set_io CSn 143
set_io MISO 141
set_io MOSI 142

set_io POT_SCLK 119
set_io POT_CSn 120
set_io POT_MOSI 118
set_io POT_SHDN 121

set_io SENSE[0] 79
set_io SENSE[1] 80
set_io SENSE[2] 81
set_io SENSE[3] 82
set_io SENSE[4] 74
set_io SENSE[5] 75
set_io SENSE[6] 76
set_io SENSE[7] 78
set_io DIR 124
set_io LED[0] 49
set_io LED[1] 83
set_io LED[2] 84
set_io LED[3] 85
set_io INHIBIT[0] 99
set_io INHIBIT[1] 98
set_io INHIBIT[2] 97
set_io INHIBIT[3] 96
set_io INHIBIT[4] 88
set_io INHIBIT[5] 87
set_io INHIBIT[6] 91
set_io INHIBIT[7] 90
set_io X0_EN_F 106
set_io X0_EN_R 105
set_io X1_EN_F 104
set_io X1_EN_R 102
set_io Y0_EN_F 117
set_io Y0_EN_R 116
set_io Y1_EN_F 115
set_io Y1_EN_R 114
set_io Y2_EN_F 113
set_io Y2_EN_R 112
set_io Y3_EN_F 110
set_io Y3_EN_R 107

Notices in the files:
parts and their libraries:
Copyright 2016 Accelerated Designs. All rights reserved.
